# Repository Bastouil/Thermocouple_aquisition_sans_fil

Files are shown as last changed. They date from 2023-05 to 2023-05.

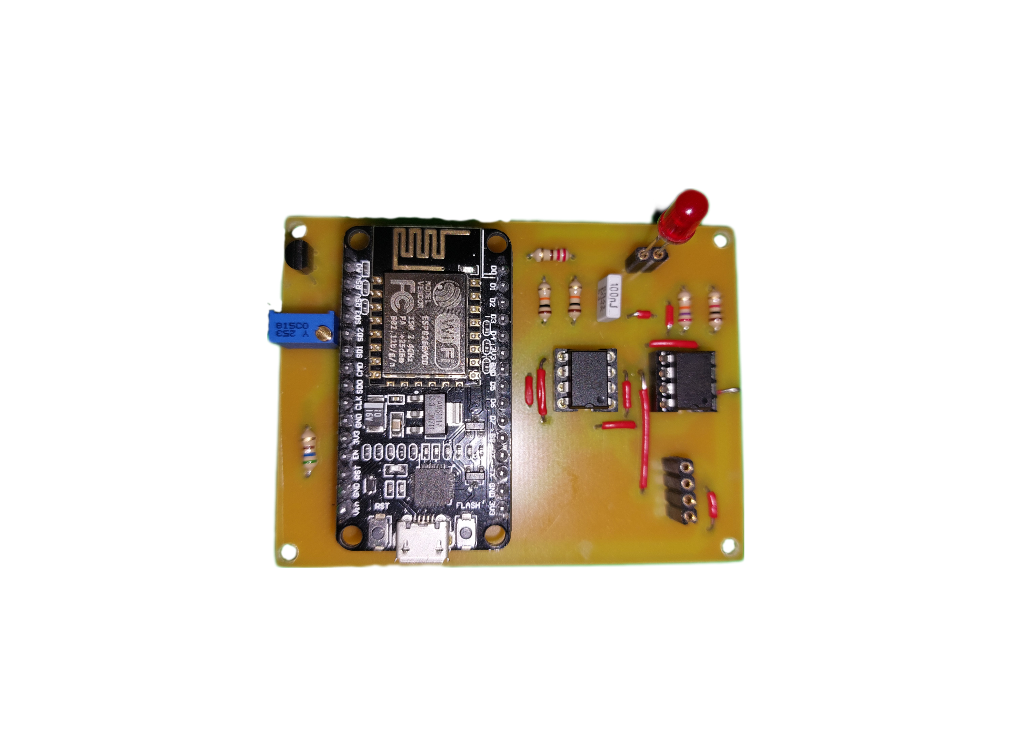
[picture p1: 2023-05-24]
Banque_images/BackgroundEraser_20230427_111905580.png

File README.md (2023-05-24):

# Thermocouple_aquisition_sans_fil
Le but du projet est de créer un thermocouple ayant un moyen d’acquisition sans fil. Les données seront envoyées par protocole WIFI afin d'être affichées et enregistrées sur un ordinateur.

La structure de l'archive du projet est la suivante :

-Banque_images :
	Dossier comprenant des photos, captures d'écran... du produit et des tests

-Circuit_imprime :
	Dossier qui contient les fichiers EAGLE du circuit électronique et du routage du PCB,
	ainsi que les fichiers PDF associés

-Datasheets :
	Dossier contenant les datasheets de chaque composant utilisé : 
	ESP8266 (nodeMCU), MCP3301, MCP6002 et LM335Z

-Documents_produits :
	Vous trouverez dans ce dossier le document de cadrage, l'énoncé du projet,
	les diapositives des 2 jalons, le rapport du projet ainsi qu'un manuel d'utilisation pour le thermocouple

-Programmes :
	Ce dossier contient un sous dossier contenant le programme entré dans le microcontroleur ESP8266
	(serveur TCP) écrit en cpp dans l'IDE ARDUINO, un second sous dossier contenant un programme principal écrit en Python
	(script client TCP lancé sur un ordinateur) faisant appel à un second programme contenant certaines fonctions pour alléger
	le code et enfin un manuel d'utilisation en pdf appelé par le code. Un code C émulant la conversion de tension en température, 	prenant en compte la compensation de la soudure froide est également contenu dans ce dossier

-Modelisation_CAO_boitier :
	Dossier comprenant les conceptions 3D sur FUSION 360 de chacun des composants du boitier,
	ainsi que la modélisation du produit

JAOUANNE Lilian & GARCON Bastian

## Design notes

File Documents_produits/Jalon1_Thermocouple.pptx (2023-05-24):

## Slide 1

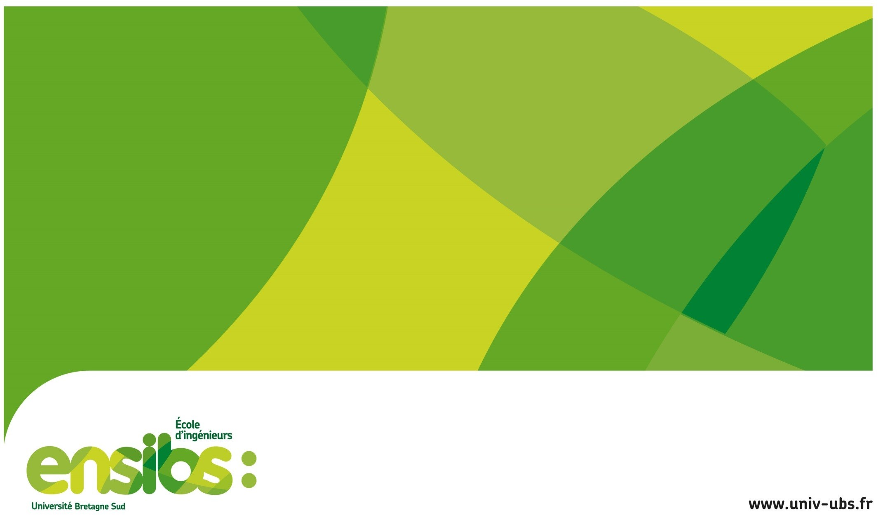
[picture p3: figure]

PRJ1401 - THERMOCOUPLE

Jalon intermédiaire
JAOUANNE Lilian
GARÇON Bastian

## Introduction

GARÇON JAOUANNE

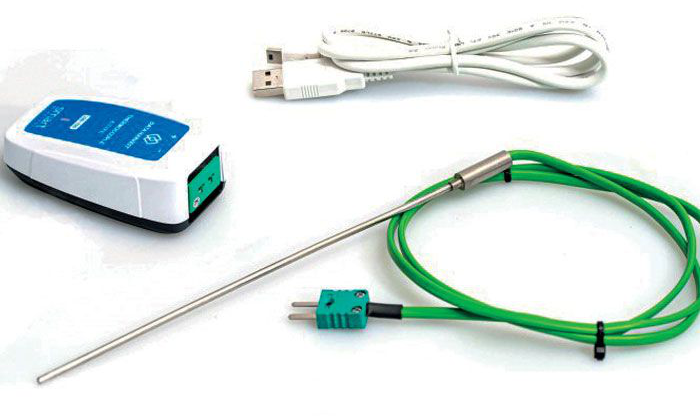
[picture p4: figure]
Bluetooth Wireless Smart K-Type Thermocouple -200°C to 1000°C / Capteur de température avec Thermocouple de type K

- Plage de températures : -200 à 1200°C
- Acquisition sans fils
- Résolution inférieur à 1°C
- Autonome en énergie

Client du projet : Hervé LAURENT, ENSIBS Mécatronique

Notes: Rappel du sujet.

## Sommaire

- Planification du projet
- Compensation soudure froide
- Conversion de la tension en température
- Matériaux utilisées
- Conversion analogique numérique de la tension
- Acquisition sans fil
- Tâches à réalisées

## Planification du projet

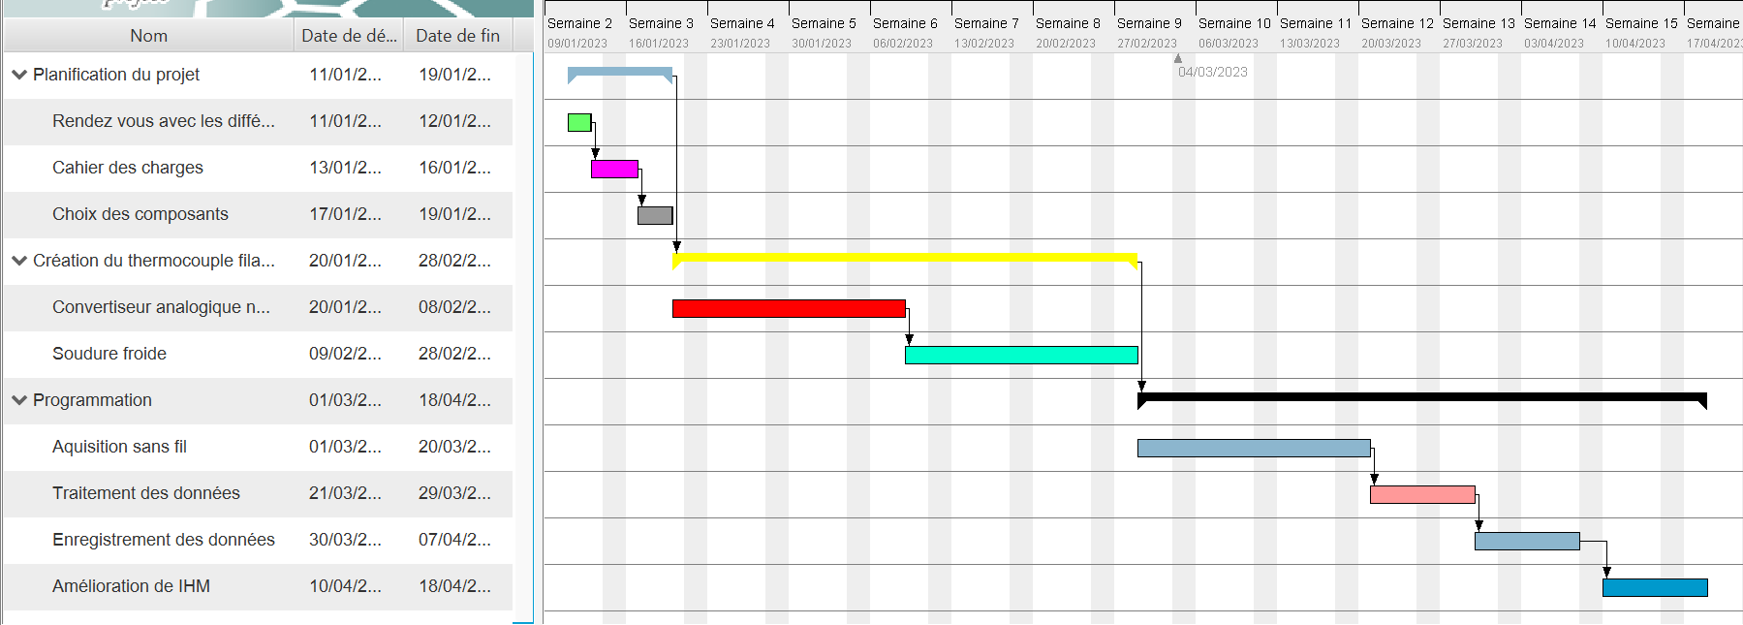
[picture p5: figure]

## Compensation soudure froide

E_(AB) (T_(0^(′)) ,T_0 )+E_(AB) (T_1 ,T_(0^(′)) )=E_(AB) (T_1 ,T_0 )

A

V

T_(0^(′))

T_1

B

Avec T_0 =0°C

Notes: Un thermocouple est un capteur actif de température. Il est composé de deux jonctions reliant deux métaux ou alliages différents. Le thermocouple fonctionne grâce à l’effet Seebeck qui produit un courant continu lorsqu'il y a une différence de température entre les deux jonctions. En ouvrant le circuit, on mesure une tension de faible niveau, mais mesurable (centaine de µV). Le thermocouple mesure la différence de température entre le point de mesure (SF – soudure froide) et le point de raccordement (SC – soudure chaude).
Température de la soudure froide doit être connu.

## Conversion tension / température

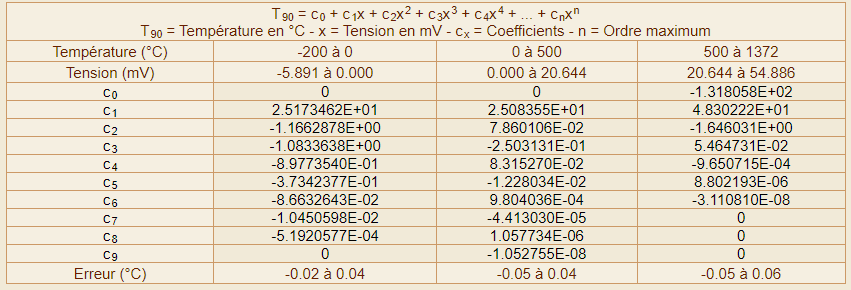
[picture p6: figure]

Tension -> Température

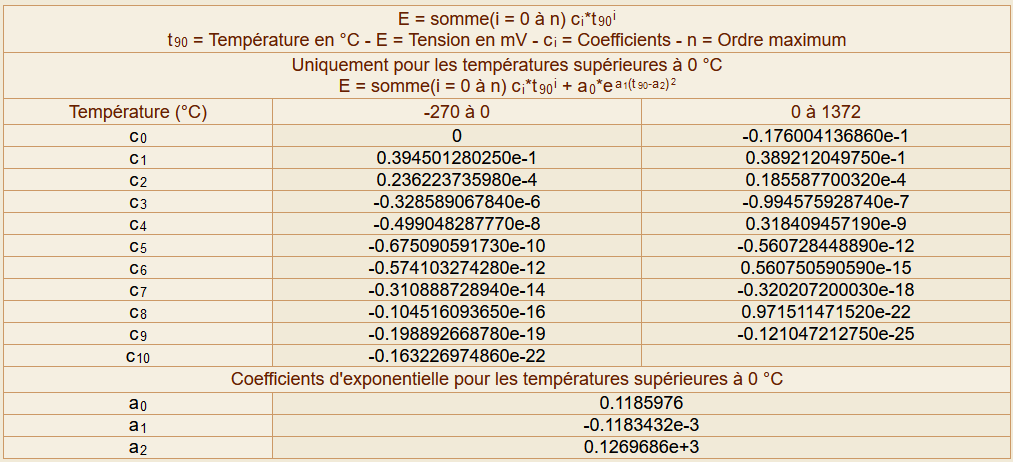
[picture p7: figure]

Température -> Tension

V

E_(AB) (T_(0^(′)) ,T_0 )+E_(AB) (T_1 ,T_(0^(′)) )=E_(AB) (T_1 ,T_0 )

## Matériaux utilisés

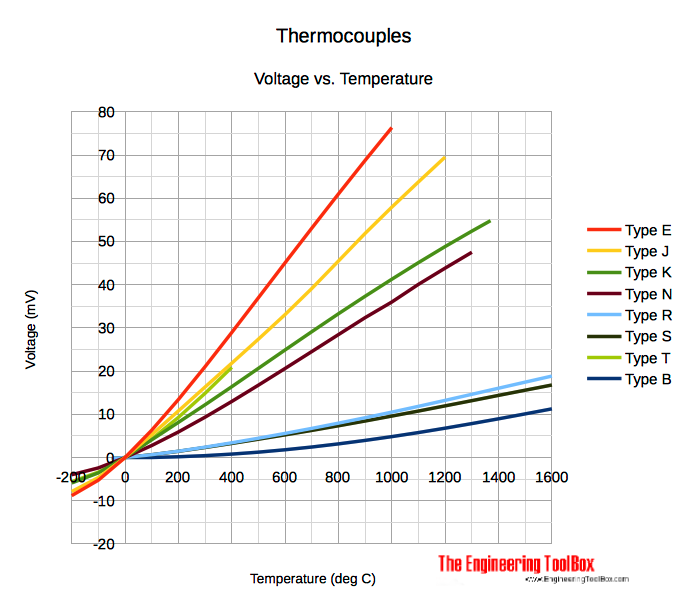
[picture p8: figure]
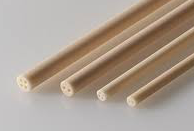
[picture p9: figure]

alumine

Chromel – Alumel (125 µm)

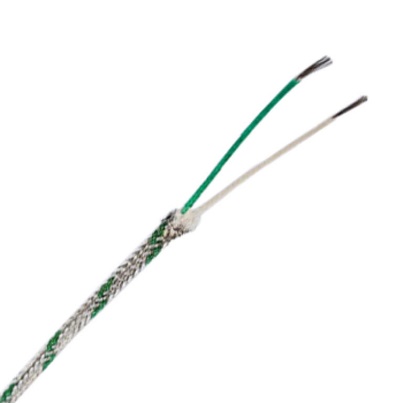
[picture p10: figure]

Soie de verre

## Conversion analogique numérique

Résolution= (Vref)/4096 = 24,4 µV avec Vref = 100 mV

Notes: Pourquoi ce choix ? CAN 12 bits + 1 bit signe, communication SPI

## Conversion analogique numérique

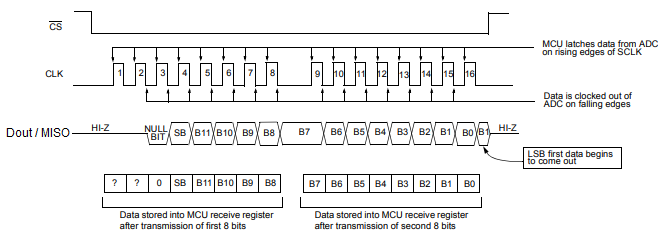
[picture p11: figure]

Mode de cadencement SPI : 0
- Polarité d’horloge (CPOL = 0) : Horloge en veille à l’état logique 0
- Phase d’horloge (CPHA = 0) : Cadencement des données sur le front montant

## Conversion analogique numérique

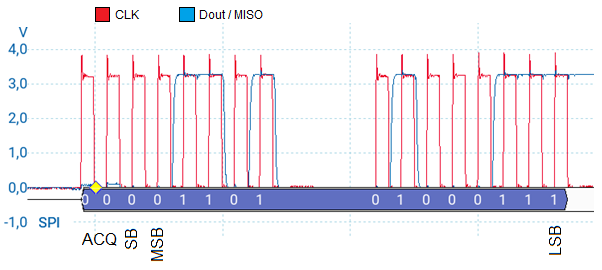
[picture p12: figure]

(0 0110 1010 0011)_(2S) = 3399_10

Tension = 3399 ×1000 × (Vref)/4095=82 mV , avec Vref = 100mV

## Acquisition sans fils

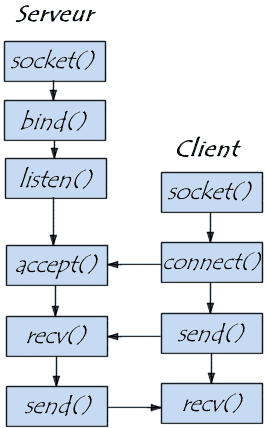
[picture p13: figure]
Déroulement d'une communication avec les sockets
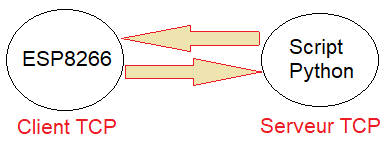
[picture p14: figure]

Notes: Choix ESP8266 point acces wifi programmé en cpp sur l’IDE Arduino

## Acquisition sans fils

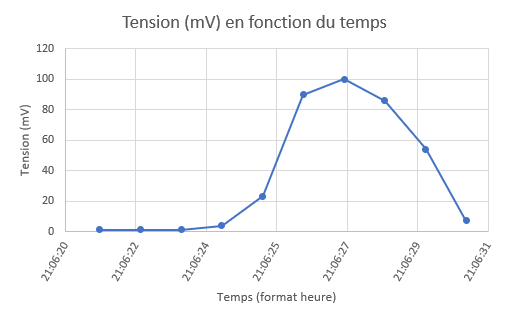
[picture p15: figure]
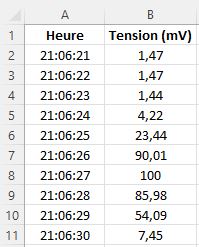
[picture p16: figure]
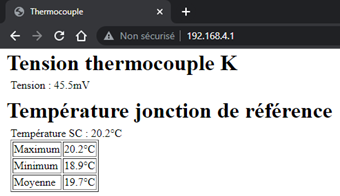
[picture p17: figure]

## Schéma électronique

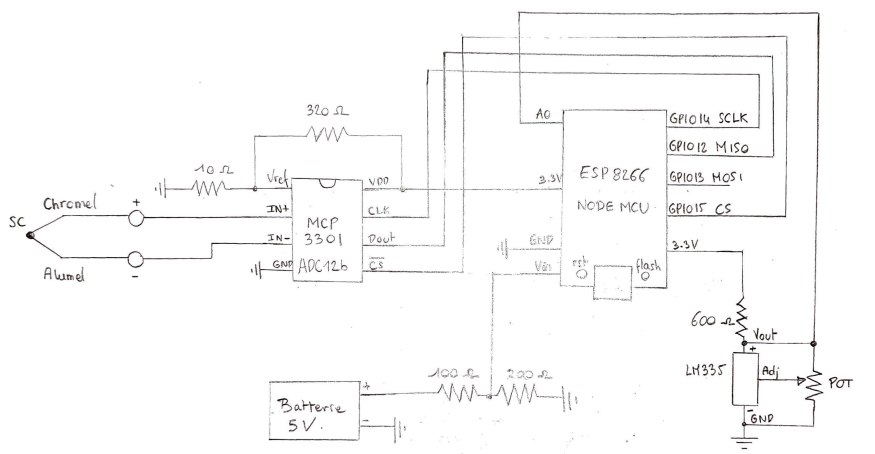
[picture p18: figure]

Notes: Conclusion de notre system et parler du capteur de température.

## Tâches à réaliser

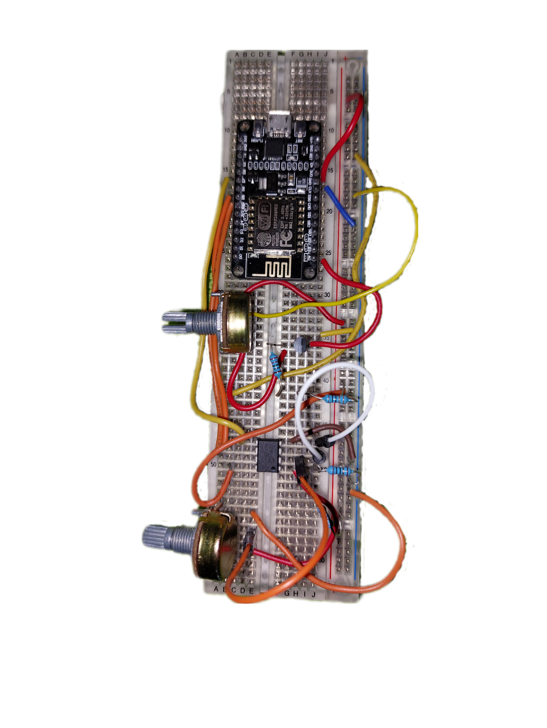
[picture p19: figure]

- Modélisation CAO d’un boîtier en PLA
- Maquettage de l’électronique (PCB)
- Alimentation
- Connecter l’ordinateur sur lequel est lancé le script au réseau wifi de l’ESP8266
- Créer un guide d’utilisation

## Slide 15

PRJ1401 - THERMOCOUPLE

Jalon intermédiaire
JAOUANNE Lilian
GARÇON Bastian

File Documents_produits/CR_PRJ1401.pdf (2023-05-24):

Lilian JAOUANNE & Bastian GARCON | 04/2023

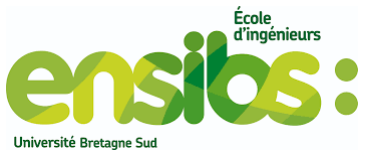
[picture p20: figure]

PEI2 / L2-SNIO – PRJ1401

# PRJ1401 : Rapport Projet Thermocouple Wifi

## Table des matières

## GARCON Bastian JAOUANNE Lilian

## I. Introduction

L’objectif de ce projet consiste à développer un thermocouple et d’acquérir la valeur de la température par un moyen sans fil (Bluetooth, Wifi…) sur une centrale d’acquisition. Le thermocouple devra pouvoir fonctionner sur une plage de température de -200 à 1200°C.

Bien que ce type de thermocouple existe déjà sur le marché, il nous ait demandé d’en concevoir un à partir des moyens disponibles à l’ENSIBS et si possible à bas coût.

## II. Principe de fonctionnement d’un thermocouple

Le principe du thermocouple consiste à mesurer une différence de potentiel entre deux fils constitués de deux conducteurs différents et soudés entre eux à une extrémité.

La mesure s’effectue ponctuellement au niveau de la soudure (nommée soudure chaude ou jonction de référence).

Un thermocouple est un capteur actif de température. Il est composé de deux jonctions reliant deux métaux ou alliages différents. Le thermocouple fonctionne grâce à l’effet Seebeck (Cf Erreur ! Source du renvoi introuvable.) qui produit un courant continu lorsqu'il y a une différence de température entre les deux jonctions. En ouvrant le circuit, on mesure une force électromotrice (tension) de faible niveau, mais mesurable (centaine de µV). Le thermocouple mesure la différence de température entre le point de mesure (SF – soudure froide) et le point de raccordement (SC – soudure chaude).

Pour s'assurer que la température ambiante aux bornes de raccordement de la soudure froide (idéalement 0°C) n'affecte pas le résultat de la mesure, une compensation de soudure froide est nécessaire.

La tolérance d’un thermocouple est généralement de ± 1°C. La soudure chaude peut être générée à partir d’un arc électrique et les fils qui composent le thermocouple (ou câbles d'extension/compensation) ont une couleur caractéristique normalisée. Le conducteur négatif est toujours blanc, le conducteur positif est toujours de la couleur de la gaine. Chaque paire de conducteurs définit une plage de mesure et un graphe associé, nommé par une lettre.

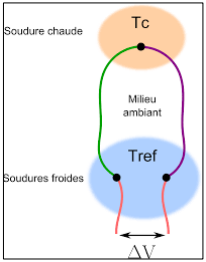
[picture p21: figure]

Figure 1 : Principe du thermocouple

## III. Définition du cahier des charges

- Plage de températures : -200 à 1200°C
- Acquisition sans fils
- Résolution correcte
- Fréquence d’échantillonnage 10Hz minimum
- Autonome en énergie

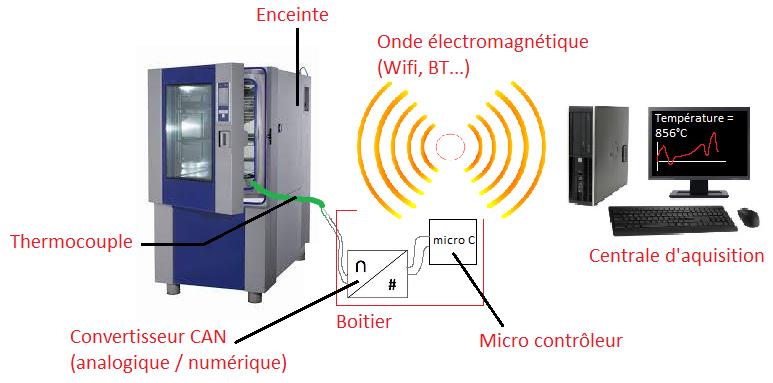
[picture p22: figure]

Figure 2 : Schéma du dispositif envisagé.

- Moyen d’acquisition

Pour le traitement du signal, il faudra un convertisseur analogique numérique (choisi en fonction de son nombre de bits) ou d’un module de récupération directe de la température devant renvoyer la donnée mesurée à un microcontrôleur. Microcontrôleur qui devra ensuite pouvoir traiter la différence de potentiel et la température de la jonction de mesure, puis transmettre la donnée par Bluetooth ou Wifi à un moyen d’acquisition (poste informatique, smartphone…).

La centrale d’acquisition devra ensuite récupérer la donnée émise et gérer son affichage.

Une solution serait le développement d’une application avec un script Python, affichant des informations sur la série de mesures dans le terminal par exemple.

- Autonomie

L’ensemble devra avoir sa propre source d’alimentation, il ne devra pas être relié à un secteur d’alimentation. De plus, le moyen d’alimentation devra assurer une durée de fonctionnement correct et répondre aux impulsions de consommations importantes demandées par le Bluetooth et le Wifi.

- Design

L’ensemble devra avoir une ergonomie compacte et discrète. Les fils du thermocouple sortiront de l’enceinte isolée thermiquement et être reliés à un boîtier situé à côté de l’enceinte (à l’extérieur). Boitier possiblement imprimé en 3D avec du PLA, dans lequel se trouveront les composants propres au traitement et à l’émission du signal.

## IV. Type de thermocouple utilisé et choix des isolants

Pour choisir notre type de thermocouple, nous nous sommes aidés du graphe en Figure 3. Premièrement, nous avons procéder par élimination grâce à la plage de température que nous impose le cahier des charges. De cette manière, nous savons que les thermocouples de types E, J et T (cf. Figure
3) ne sont pas envisageable puisque leur plage de fonctionnement s’arrête avant 1200 °C.

Nous avons donc le choix entre les 5 autres thermocouples (types K, R, N, S et B).

Finalement, nous avons choisi d’utiliser un thermocouple de type K car c’est celui qui possède la plus grande variation de tension en fonction de la température. Ce critère est important puisqu’il influera sur la précision de notre thermocouple.

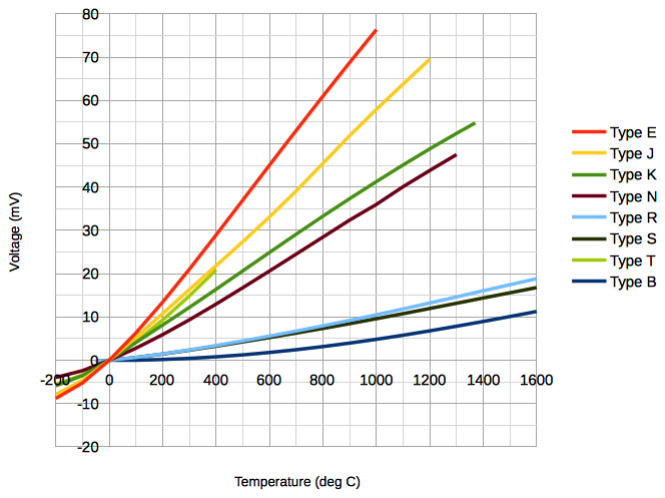
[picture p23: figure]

Figure 3 : courbes de tensions en fonction de la température pour différents types de thermocouples.

Concernant le choix des isolants, nous avons choisi d’utiliser un tube d’alumine (cf. Figure 4) pour le bout du thermocouple car l’alumine est un isolant électrique résistant à de très haute température (1800°C). Pour le reste de la gaine, nous utilisons de la soie de verre (cf. Figure 5) puisque que contrairement à l’alumine, la soie de verre est plutôt flexible ce qui rend la manipulation de la gaine plus simple pour les mesures de température. En revanche, la soie de verre se cristallise à partir d’environ 600 °C. C’est pourquoi nous ne l’avons pas utilisée pour l’ensemble de la gaine.

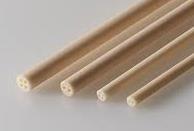
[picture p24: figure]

Figure 4 : tubes d'alumines.

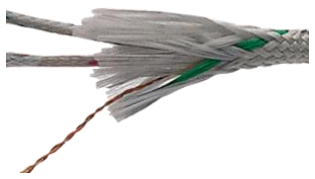
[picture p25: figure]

Figure 5 : soie de verre.

## V. Compensation de la soudure froide

La compensation de la soudure froide est une étape incontournable dans la création d’un thermocouple puisque la tension aux bornes de la soudure chaude va dépendre de la température de la soudure froide. De plus dans les tableaux de conversions pour un type de thermocouple donné, on considère que la température de la soudure froide est de 0°C.

A partir de la tension aux bornes de la soudure chaude et de la température aux bornes de la soudure froide, il est possible de compenser cette dernière grâce à la formule suivante :

EAB(T0
′ , T0

) + EAB(T1, T0

′ ) = EAB(T1, T0

)

Avec :

- EAB(T0
′ , T0

) : la tension virtuelle de la soudure froide¹
- EAB(T1, T0

′ ) : la tension aux bornes de la soudure chaude
- EAB(T1, T0

) : la tension aux bornes de la soudure chaude compensée

On obtient alors la tension compensé EAB(T1, T0

), qu’il noussuffit de convertir en température à l’aide des tables de conversion du type de thermocouple utilisé afin d’obtenir la température absolue à la soudure chaude.

Pour connaître la température de la soudure froide (approximée à la température ambiante dans le boîtier du thermocouple), nous utilisons un capteur de température LM335Z avec le montage suivant (cf. Figure 6) :

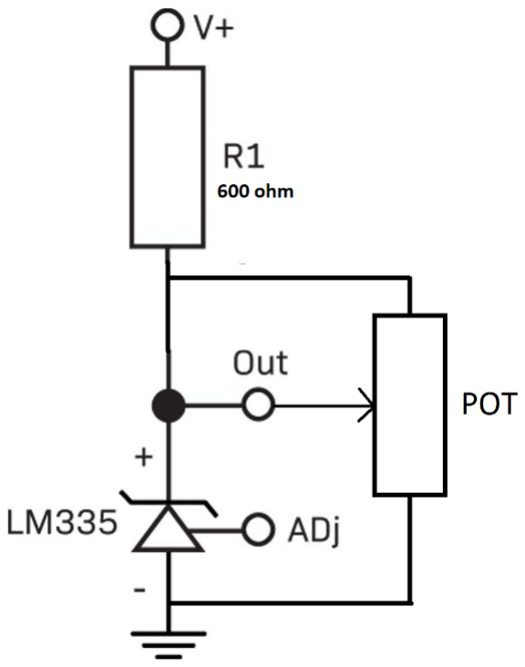
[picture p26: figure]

Figure 6 : Schéma circuit LM335.

Un potentiomètre (cf. Figure 6, POT) permet de calibrer manuellement la valeur de la température relevée.

1 Tension obtenue en convertissant la température de la soudure froide à l’aide des tables de conversion du type de thermocouple utilisé

## VI. Schéma électronique

### 1. Circuit d’amplification

Pour mesurer la tension aux bornes de la soudure chaude avec une précision suffisante²
, nous
devons utiliser un circuit d’amplification. Pour cela, nous utilisons premièrement un montage différentiel (cf. Figure 7, cercle rouge) pour amplifier le signal et un montage suiveur (cf. Figure 7, cercle vert) pour stabiliser la tension « Offset » qui va permettre de mesurer des tensions négatives.

Vref

Figure 7 : schéma du circuit d'amplification.

En considérant les propriétés des AOP, on trouve le gain G suivant :

G =

R1 + R2
R1

En sachant que les tensions que mesurera notre thermocouple vont de -5,891 mV (pour une soudure chaude à -200 °C) à 48,838 mV (pour une soudure chaude à 1200 °C) et que notre convertisseur analogique numérique ne mesurera des valeurs allant de 0 à 3,3V, nous devrons alors avoir un gain d’environ :

2 ± 42 µV pour avoir une pression de ± 1 °C

3300 − 0
48,838 − (−5,891)

≈ 60

En sachant que nous ajoutons une tension « Offset » de ³,3
2

pour amplifier les tensions négatives, nous devrons donc amplifier avec une valeur étant aux alentour de 30 (la moitié de 60). Pour être sûr que notre AOP ne sature pas, on prend un gain légèrement inférieur à 30.

Sur la Figure 7 on voit que notre gain est de :

1 + 27
1

= 28

Dans la pratique, notre gain est d’environ 28,11 puisque les résistances R1 et R2 ne font pas exactement 1 kΩ et 27 kΩ.

Pour tester le circuit d’amplification, nous avons généré des signaux continus d’amplitudes comprises entre -6 mV et 50 mV (plage de tension du thermocouple de type K) à l’aide d’un Picoscope 2000.

### 2. Conversion analogique numérique

L’unique entrée analogiques du microcontrôleur ESP8266 n’étant codée que sur 10 bits (2

10 =
1024 valeurs possibles) et l’ESP8266 étant alimenté en 3,3V soit 3300 mV, cette entrée nous donne donc une résolution de ³³⁰⁰
1024

≈ 3,22 mV.

Or, la plage de tension en sortie du thermocouple pour des températures allant de -200 à 1200°C (amplitude de 1400°C) est comprise entre -5 et 50 mV soit une amplitude de valeurs de 55 mV. Avec une résolution de 3,22 mV, nous aurions alors pour une plage de tension de 55 mV, 55
3,22

≈ 17,08
valeurs possibles.

Ce qui correspond à une résolution en température de 1400
17,08

≈ 82°C sans l’utilisation d’AOP.

Par soucis de précision, nous utiliserons donc le convertisseur analogique 13 bits MCP3301 avec communication SPI. Cet ADC est codé sur 12 bits avec en plus un bit de signe. Alimenté en 3,3 V, il nous donnera donc une résolution de ³³⁰⁰
2

13 ≈ 0,4 mV et donc

55
0,4

≈ 137,5 valeurs possibles. Il nous donne donc une résolution en température de 1400
| 137,5 ≈ 10°C sans AOP.

Le MCP3301 (esclave) communiquera avec l’ESP8266 (maitre) suivant le protocole de communication SPI mode 0.

Mode de cadencement SPI : 0

- Polarité d’horloge (CPOL = 0) : Horloge en veille à l’état logique 0
- Phase d’horloge (CPHA = 0) : Cadencement des données sur le front montant

Un pin CS (chip select) de sélection de puce permet lorsqu’il est forcé à l’état bas, d’activer la communication avec le maitre (ESP8266). La trame (cf. Figure 8) envoyée sur la sortie MISO (master input slave output) permet l’échange de données (valeur de tension différentielle en entrée du convertisseur) vers le maitre, cadencé par une horloge CLK.

Remarque : Le MCP3301 ne comporte pas de pin MOSI (master output slave input), rendant ainsi impossible l’envoi de données du maitre vers l’ADC.


Figure 8 : détail de la trame du MCP3301.

La fréquence d’horloge du MCP3301 est fclk = 1,7 MHz et une trame est codée sur 17 cycles d’horloges. On en déduit que la fréquence d’échantillonnage du convertisseur est fsamples =

fclk
17

=
100 kHz.

Un exemple de trame SPI décodée au Picoscope est le suivant (cf. Figure 9) :


Figure 9 : trame SPI décodée au Picoscope.

On a alors : (0 0110 1010 0011)2S = 339910

Et Tension = 3399 × 1000 ×

Vref
4096

= 2738 mV, avec Vref = 3,3 V

Note : Vref est une broche du composant qui prend en entrée une tension de référence qui influe directement sur la résolution du convertisseur

### 3. Création d’un PCB

Le PCB a été fait à l’aide du logiciel EAGLE. Nous avons commencé par faire notre schéma électronique (cf. Figure 10) puis nous avons dû router(créer des pistes de cuivre pour relier les broches des composants) le PCB avant son impression (cf. Figure 11). Le PCB à deux couches, une couche appelée « bottom » constituée de pistes de cuivre et une couche côté composant « top » sur laquelle on utilise des fils apparents pour faire les liaisons. Des vias permettent de faire le lien entre certaines pistes de la couche « bottom » et de celles de la couche « top ».


Figure 10 : schéma électronique du thermocouple sous EAGLE.


Figure 11 : routage du PCB sous EAGLE.


Figure 12 : Photos du PCB après les soudures des connecteurs et l’ajout des composants.

## VII. Alimentation du thermocouple

L’ESP8266 dispose d’un régulateur linéaire de tension vers 3,3 V. La consommation du microcontrôleur est de 300 mA en mode point d’accès Wifi (Le mode AP empêche les modes de veilles). Nous avons choisi des pile AAA non rechargeable pour l’alimentation de notre système.

En sachant les informations suivantes :

Tension : 1,5 V

Capacité : 2500 mAh

3 piles AAA de 1,5 V en série ⇔ 4,5 V

Nous avons pu déduire l’autonomie de notre système lorsque celui-ci utiliser le Wifi.

2500
300 ≈ 8h 30min

Notre système peut donc fonctionner pendant 8h30 avec le Wifi de l’ESP8266 d’activé.

Remarque : Des piles AAA rechargeables pourraient aussi être envisagées. Ayant individuellement une tension nominale de 1,2 V, il serait judicieux d’en mettre 4 en série de sorte à obtenir une tension d’alimentation de 4,8 V (de sorte à anticiper la décharge des piles).

## VIII. Modélisation 3D du boitier

Le PCB modélisé sur EAGLE à pu être importé sur FUSION 360 (deux logiciels de la suite AUTODESK).

L’assemblage comprend un boitier, un couvercle, un interrupteur permettant d’alimenter ou non le circuit ainsi qu’un connecteur femelle de thermocouple de type K destiné à connecter les deux fils (chromel et alumel) du thermocouple.


Figure 13 : modélisation du boitier sous fusion 360.

## IX. Programmation de l’ESP8266


Figure 14: schéma serveur client.

Le script python connecté au point d’accès WiFi établi une connexion TCP avec le serveur.

Des tables de conversions propres aux thermocouples de type K permettent de retrouver la température de la soudure chaude.

Note : Bien que la fréquence d’échantillonnage du convertisseur analogique numérique MCP3301 soit de 100 kHz, on réduira la fréquence d’acquisition de la mesure à 10 Hz soit 100 ms ou encore 0,1 seconde, pour que le script Python lancé sur un ordinateur puisse correctement réceptionner les données par Wifi.

## X. Application Python

L’application a été écrite en Python avec la bibliothèque TKINTER permettant l’affichage de fenêtres.

Le fichier au format PY a ensuite été converti en EXE grâce à la commande «auto-py-to-exe» dans la console de Visual Studio Code.

Une fois l’application lancée, la fenêtre suivante s’ouvre (cf. Figure 15) :


Figure 15 : interface principale de l'application.

L’ordinateur sur lequel est lancé l’application doit être connecté au réseau Wifi généré par l’ESP8266 :

Note : Un manuel d’utilisation permettant la prise en main du logiciel et du dispositif thermocouple est disponible depuis l’onglet Aide/Utilisation de l’application.

Les données résultantes de l’acquisition Wifi sont alors enregistrées dans un fichier suivant la norme CVS (compatible avec le format XLS d’EXCEL) (exemple en Figure 16).

Figure 16 : exemple d'ouverture d'un fichier CSV avec Excel.

La première colonne du tableau (cf. Figure 16) correspond à l’horloge de la réception des trames Wifi par l’application (script python lancé sur un ordinateur) et la seconde colonne nous donne quant à elle la température mesurée localement. Il est alors possible de traiter ses données en traçant un graphique comme en Figure 17 :


Figure 17 : exemple de graphique Excel avec les données en Figure 16.

## XI. Conclusion

Ce projet nous aura permis de travailler en groupe touchant aux trois domaines fondamentaux de la mécatronique. Nous aurons notamment pu nous familiariser avec des logiciels de la suite AUTODESK et utiliser le matériel / machines de l’atelier de l’ENSIBS.

D’éventuelles reprises du projet pourraient être envisagées :

- Passer l’ESP8266 en mode station Wifi de sorte à pouvoir le déconnecter du réseau et ainsi utiliser les différents modes de veilles
- Compatibilité avec d’autres types de thermocouples (K, J, E…) sélectionnables depuis l’application

## XII. Ressources et personnel sollicités

### 1. Ressources

Pour ce projet, nous avons utiliser les différents outils présents au sein de l’ENSIBS de Lorient notamment ceux se trouvant dans le laboratoire de mécatronique (CNC pour le PCB).

Pour le matériel, nous avons pu prélever les composants prévus à cet effet, pour la fabrication de notre thermocouple à l’ENSIBS.

Enfin, si le matériel n’est pas disponible au sein de l’école. Nous avons pu en commander sur les sites partenaires.

Liens ressources :

- https://fr.wikipedia.org/wiki/Thermocouple, consulté le 15/01/2023
- https://www.youtube.com/watch?v=7QFdb2aJn14, consulté le 03/02/2023
- https://aviatechno.net/thermo/thermo03.php, consulté le 03/02/2023

Liens des images :

- Figure 3 : https://www.engineeringtoolbox.com/thermocouples-d_496.html, consulté le 26/02/2023
- Figure 4 : https://www.umicore-ceramics.com/fr/produits-en-ceramiques-techniques/tubes-en-alumine/capillaire-alumine, (https://www.umicore-ceramics.com/fr/produits-en-ceramiques-techniques/tubes-en-alumine/capillaire-alumine) consulté le 16/03/2023
- | Figure | 5 : | https://www.sab-cable.eu/produits/cables-de-compensation-dextension/th-
lgs.html, (https://www.sab-cable.eu/produits/cables-de-compensation-dextension/th-lgs.html) consulté le 10/05/2023

### 2. Personnel

Lors de ce projet, nous nous sommes référés à différentes personnes spécialistes dans leur domaine afin d’obtenir des précisions sur différents sujets. Avec notamment :

- Hervé LAURENT tuteur / client du projet. Il nous a notamment apporté des précisions sur le cahier des charges, suivie générale du projet et visite du laboratoire LAB-STICC.
- William BERCKMANS qui est un chercheur au LAB-STICC. Il est un spécialiste des thermocouples. Il nous a donc éclairé pour la conception de celui-ci (épaisseur des fils, choix du matériau, soudage…) et nous aussi donné du matériel (lecteur de thermocouple, câbles de thermocouple, connecteur …).
- Philippe GICQUEL, aide portée sur le circuit d’amplification des AOP (MCP6002), la modélisation du circuit électronique sur EAGLE ainsi que l’impression du PCB à la CNC.
- Florent DE LAMOTTE professeur de Mécatronique, aide concernant le choix de l’alimentation au vu de la consommation de l’ESP8266 et des éventuels modes de veilles du microcontrôleur.
- Cédric SEGUIN, professeur à l’ENSIBS. Aide sur l’envoi des trames SPI du MCP3301 (ADC 13 bits) et décodage avec un Picoscope 2000.

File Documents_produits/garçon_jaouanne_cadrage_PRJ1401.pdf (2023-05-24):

JAOUANNE Lilian GARÇON Bastian | 13 janvier 2023
L2 SNIO / PEI2 | 1

## PRJ 1404

### GARÇON Bastian & JAOUANNE Lilian

### Client : LAURENT Hervé

__________________________________________________________________________________

## Table des matières

## Objectif :

L’objet de ce projet consiste à développer un thermocouple et d’acquérir la valeur de la température par un moyen sans fil (Bluetooth, Wifi…) sur une centrale d’acquisition. Le thermocouple devra pouvoir fonctionner sur une plage de température de -200 à 1200°C.

Bien que ce type de thermocouple existe déjà sur le marché, il nous ait demandé d’en concevoir un à partir des moyens disponibles à l’ENSIBS et si possible à bas coût.

# Thermocouple Document de cadrage


L2 SNIO / PEI2 | 2

## Fonctionnement du thermocouple :

Le principe du thermocouple consiste à mesurer une différence de potentiel entre deux fils constitués de deux conducteurs différents et soudés entre eux à une extrémité.

La mesure s’effectue ponctuellement au niveau de la soudure (nommée soudure chaude ou jonction de référence).

Un thermocouple est un capteur actif de température. Il est composé de deux jonctions reliant deux métaux ou alliages différents. Le thermocouple fonctionne grâce à l’effet Seebeck (Cf Bibliographie) qui produit un courant continu lorsqu'il y a une différence de température entre les deux jonctions. En ouvrant le circuit, on mesure une force électromotrice (tension) de faible niveau, mais mesurable (centaine de µV). Le thermocouple mesure la différence de température entre le point de mesure (SF – soudure froide) et le point de raccordement (SC – soudure chaude).

Pour s'assurer que la température ambiante aux bornes de raccordement de la soudure froide (idéalement 0°C) n'affecte pas le résultat de la mesure, une compensation de soudure froide est nécessaire.

La tolérance d’un thermocouple est généralement de ± 1°C. La soudure chaude peut être générée à partir d’un arc électrique et les fils qui composent le thermocouple (ou câbles d'extension/compensation) ont une couleur caractéristique normalisée. Le conducteur négatif est toujours blanc, le conducteur positif est toujours de la couleur de la gaine. Chaque paire de conducteurs définit une plage de mesure et un graphe associé, nommé par une lettre.

Figure 1 : Principe du thermocouple


L2 SNIO / PEI2 | 3

## Cahier des charges :

Figure 2 : Schéma du dispositif envisagé

- Thermocouple

Il existe différents types de thermocouples suivant la plage de température à mesurer, différenciant le couple de matériaux semi-conducteurs à utiliser.

Nous prendrons un thermocouple de type K pour des températures allant de -270 à 1370°C avec une sensibilité de 41µV/°C. Le type K demande un fil de Chromel (alliage de Nickel et de Chrome) et un fil d’Alumel (alliage de Nickel et d’Aluminium).

La taille des 2 fils utilisés influencera sur la vitesse et la précision des mesures. Nous préférerons donc des fils fins et prendrons des fils de 250 microns.

Pour isoler électriquement nos deux fils, nous utiliserons un tube d’alumine (minéraux de température de fusion 2000°C) pour la partie à l’intérieur de l’enceinte et une isolation en soie de verre pour la partie des fils à l’extérieur (fusion à 300°C).

Pour compenser la température de référence de la soudure froide, il est nécessaire de connaître la température de la jonction de référence. On utilisera pour cela une thermistance CTN ou autre capteur de température.

- Moyen d’acquisition

Pour le traitement du signal, il faudra un convertisseur analogique numérique (choisi en fonction de son nombre de bits) ou d’un module de récupération directe de la température devant renvoyer la donnée mesurée à un microcontrôleur. Microcontrôleur qui devra ensuite pouvoir traiter la différence

L2 SNIO / PEI2 | 4

de potentiel et la température de la jonction de mesure, puis transmettre la donnée par Bluetooth ou Wifi à un moyen d’acquisition (poste informatique, smartphone…).

La centrale d’acquisition devra ensuite récupérer la donnée émise et gérer son affichage.

Une solution serait le développement d’une application avec un script Python, affichant des informations sur la série de mesures dans le terminal par exemple.

- Autonomie

L’ensemble devra avoir sa propre source d’alimentation, il ne devra pas être relié à un secteur d’alimentation. De plus, le moyen d’alimentation devra assurer une durée de fonctionnement correct et répondre aux impulsions de consommations importantes demandées par le Bluetooth et le Wifi.

- Design

L’ensemble devra avoir une ergonomie compacte et discrète. Les fils du thermocouple sortiront de l’enceinte isolée thermiquement et être reliés à un boîtier situé à côté de l’enceinte (à l’extérieur). Boitier possiblement imprimé en 3D avec du PLA, dans lequel se trouveront les composants propres au traitement et à l’émission du signal.

L2 SNIO / PEI2 | 5

## Ressource et personnel mis à notre disposition

### Ressources

Pour ce projet, nous pourrons utiliser les différents outils présents au sein de l’ENSIBS de Lorient notamment ceux se trouvant dans le laboratoire de mécatronique. Si nécessaire, nous devrons être supervisés par un enseignant lors de l’utilisation de ces derniers.

Pour le matériel, nous pourrons prélever les composants prévus à cet effet, pour la fabrication de notre thermocouple à l’ENSIBS.

Enfin, si le matériel n’est pas disponible au sein de l’école. Nous pourrons en commander sur les sites partenaires.

### Personnel

Lors de ce projet, nous pourrons aussi nous référer à différentes personnes spécialistes dans leur domaine afin d’obtenir des précisions sur différents sujets. Cela a déjà été le cas avec l’un des chercheurs au LAB-STICC, William BERCKMANS. William est un spécialiste des thermocouples. Il nous a donc éclairé pour la conception de celui-ci (épaisseur des fils, choix du matériau, soudage…) et nous aussi déjà donné du matériel (lecteur de thermocouple et câbles de thermocouple) pour débuter notre projet.

Quant à notre tuteur Hervé LAURENT, un mail lui sera envoyé après chaque session de projet. Avec à l’intérieur quelques phrases sur ce que nous avons fait durant la séance, mais aussi ce qu’il nous reste à faire pour les séances à venir. Quelquesrendez-vous seront aussi pris avec Hervé afin de faire le point sur l’avancement du projet.


L2 SNIO / PEI2 | 6

## Calendrier

date | événement du projet
lundi 12 décembre | début de la diffusion des sujets
vendredi 6 janvier | présentation du fonctionnement et des sujets
lundi 9 janvier | retour et diffusion des affectations étudiants/projets
vendredi 13 janvier | première séance de projet
vendredi 13 janvier | fin prises de rendez-vous et rencontre avec les tuteurs
vendredi 20 janvier | dépôt du document de Cadrage
vendredi 10 mars | dépôt diaporama du jalon
semaine 11 | jalon
vendredi 5 mai | dépôt diaporama de la soutenance
semaine 19 | soutenance
vendredi 12 mai | dépôt du rapport
vendredi 12 mai | dépôt de l’archive de reprise du projet

Tableau 1 : calendrier du projet

Figure 3 : Planification du projet fait sur GanttProject

L2 SNIO / PEI2 | 7

## Bibliographie

- EFFET SEEBECK
https://fr.wikipedia.org/wiki/Effet_Seebeck
- THERMOCOUPLE
https://fr.wikipedia.org/wiki/Thermocouplehttps://youtu.be/7QFdb2aJn14

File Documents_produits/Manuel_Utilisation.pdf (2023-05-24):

Lilian JAOUANNE & Bastian GARCON | 04/2023


PEI2 / L2-SNIO – PRJ1401

# Manuel d’utilisation

1. Mise sous tension du dispositif thermocouple en faisant basculer la position de l’interrupteur présent sur le boitier.


2. Brancher le connecteur du thermocouple de type K au bornier du boitier.

# Thermocouple WiFi


3. Lancer l’application « ThermoWiFi » sur un ordinateur, puis connecter l’ordinateur en question au point d’accès WiFi généré par l’ESP8266 du dispositif du thermocouple à l’aide des informations suivantes :
- SSID : Thermocouple-WiFi
- Password : ENSIBS2023


4. Calibrer le capteur de température de la soudure froide du thermocouple depuis la barre de menu de l’application sous « Réglages » puis « Soudure froide ».


Ouvrir le boitier du thermocouple et se munir d’un tournevis pour faire tourner le potentiomètre présent sur le circuit intégré du thermocouple, jusqu’à obtenir sur la valeur de la température ambiante dans la fenêtre de l’application, puis fermer la fenêtre.


5. Choisir un fichier au format « csv » (format Excel) dans lequel sauvegarder les valeurs lors de la mesure.
La sélection / création du fichier se fait depuis la barre de menu sous « Fichier » puis « Enregistrer ». Le chemin du fichier courant doit alors être affiché sur la fenêtre principale de l’application.
6. Lancer l’acquisition de données en cliquant sur le bouton « Start » et arrêter l’acquisition une fois les mesures effectuées en cliquant sur le bouton « Stop ». Remarque : La LED présente sur dessus du boitier du thermocouple clignotera durant l’acquisition.


7. Vous pouvez ensuite consulter / mettre en forme les données obtenues (valeurs de températures de la soudure chaude (en °C) en fonction du temps (en ms)) directement depuis l’application sous « Fichier » puis « Ouvrir » ou depuis votre explorateur de fichiers.


8. Des informations sur l’applications se trouvent dans la barre de menu sous « Aides » puis « A propos ».
9. Des informations complémentaires concernant l’utilisation de l’application se trouvent dans l’onglet « Aides » puis « Utilisation » de la barre de menu.

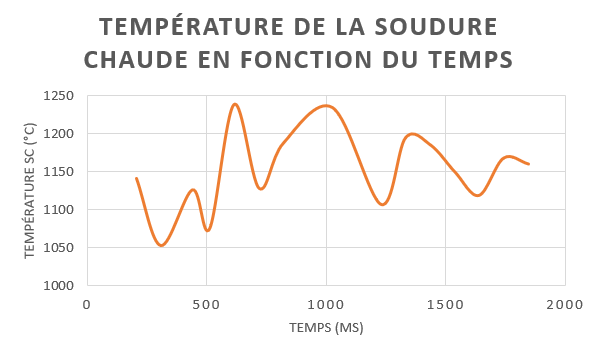
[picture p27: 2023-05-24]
Banque_images/graph.png

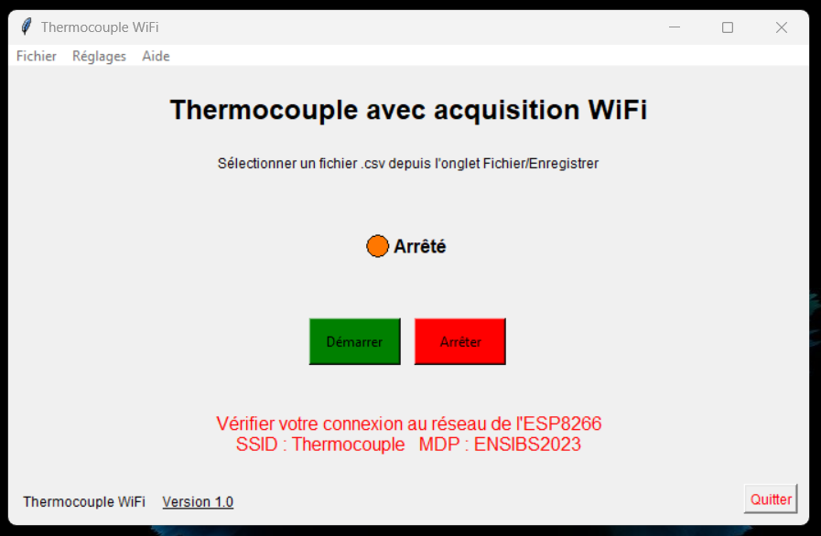
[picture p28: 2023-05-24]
Banque_images/erreur_connexion.png

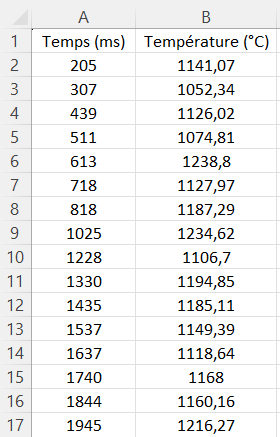
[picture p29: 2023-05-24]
Banque_images/donnees_excel.png

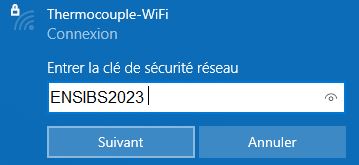
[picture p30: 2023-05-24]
Banque_images/connexion_wifi.JPG

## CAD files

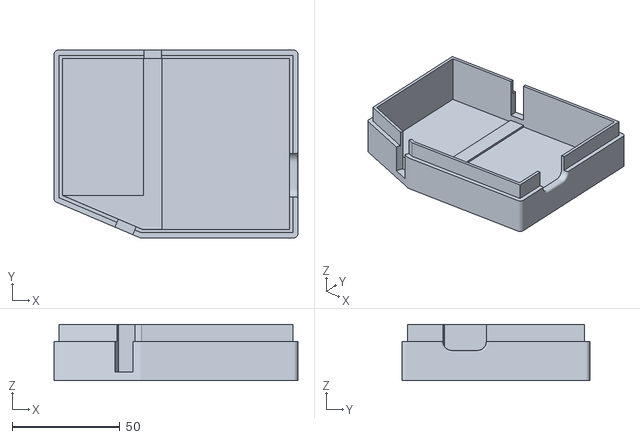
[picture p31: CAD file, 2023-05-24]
Modelisation_CAO_boitier/Boitier_ThermocoupleVF.STL
113.0 x 87.0 x 26.0

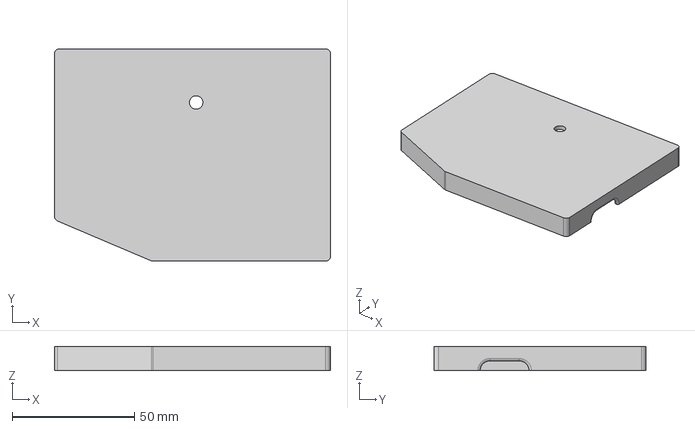
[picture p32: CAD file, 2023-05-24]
Modelisation_CAO_boitier/Couvercle_Thermocouple.step
113.0 x 87.0 x 10.0 mm

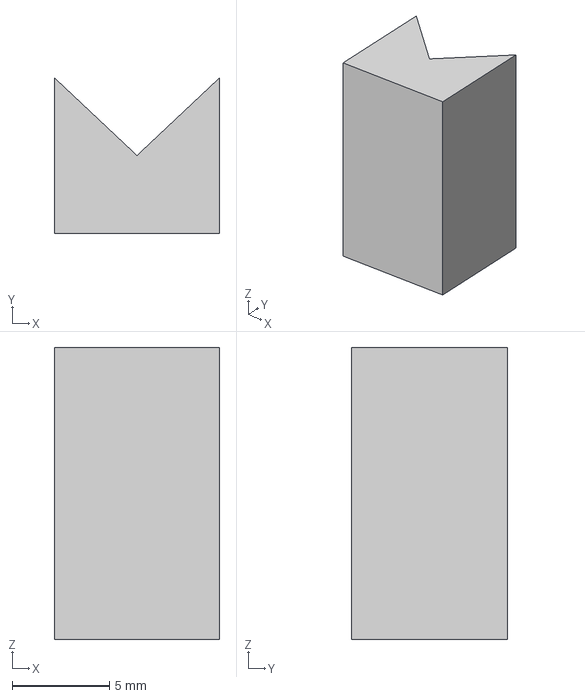
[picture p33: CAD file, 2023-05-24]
Modelisation_CAO_boitier/socle v1.step
8.50 x 8.00 x 15.0 mm

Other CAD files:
Modelisation_CAO_boitier/socle.STL
Modelisation_CAO_boitier/Assemblage_Thermocouple/0204_7.ipt
Modelisation_CAO_boitier/Assemblage_Thermocouple/1725672-4-2.54.ipt
Modelisation_CAO_boitier/Assemblage_Thermocouple/1x3 Male Pin Header.ipt
Modelisation_CAO_boitier/Assemblage_Thermocouple/1x4 Male Pin Header.ipt
Modelisation_CAO_boitier/Assemblage_Thermocouple/Assemblage_Thermocouple_V1.iam
Modelisation_CAO_boitier/Assemblage_Thermocouple/Board.ipt
Modelisation_CAO_boitier/Assemblage_Thermocouple/Boitier_3-piles-AAA v1.ipt
Modelisation_CAO_boitier/Assemblage_Thermocouple/Boitier_Thermocouple_V1 v6.ipt
Modelisation_CAO_boitier/Assemblage_Thermocouple/C050-025X075.ipt
Modelisation_CAO_boitier/Assemblage_Thermocouple/Connecteur_Thermocouple_femelle v1.ipt
Modelisation_CAO_boitier/Assemblage_Thermocouple/Couvercle_Thermocouple_V1 v11.ipt
Modelisation_CAO_boitier/Assemblage_Thermocouple/DIL08.ipt
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

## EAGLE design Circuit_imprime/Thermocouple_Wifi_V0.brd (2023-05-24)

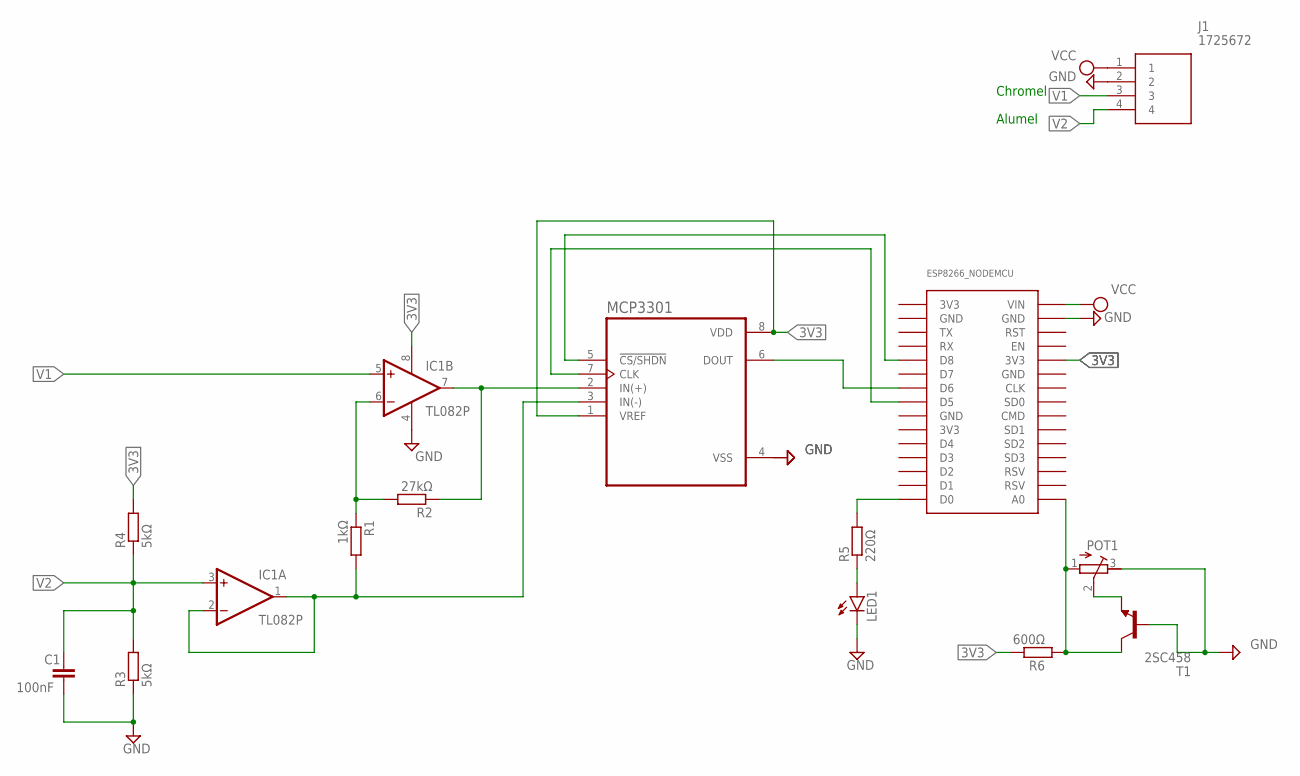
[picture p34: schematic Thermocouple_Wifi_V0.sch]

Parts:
C1: 100nF; C050-025X075
ESP8266_NODEMCU: NODEMCU_ESP8266
IC1: TL082P; DIL08
J1: 1725672; 1725672-4-2.54
LED1: LED5MM
MCP3301: MCP3301-CI/P; DIP787W46P254L927H533Q8
POT1: R-TRIMM74W; RTRIM74W
R1: 1kΩ; 0204/7
R2: 27kΩ; 0204/7
R3, R4: 5kΩ; 0204/7
R5: 220Ω; 0204/7
R6: 600Ω; 0204/7
T1: 2SC458; TO92-ECB

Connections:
3V3: ESP8266_NODEMCU.3V3@1 (3V3), ESP8266_NODEMCU.3V3@2 (3V3), ESP8266_NODEMCU.3V3@3 (3V3), IC1.8 (V+), MCP3301.1 (VREF), MCP3301.8 (VDD), R4.2, R6.2
GND: C1.2, ESP8266_NODEMCU.GND@1 (GND), ESP8266_NODEMCU.GND@2 (GND), ESP8266_NODEMCU.GND@3 (GND), ESP8266_NODEMCU.GND@4 (GND), IC1.4 (V-), J1.2, LED1.K (C), MCP3301.4 (VSS), POT1.3 (E), R3.1, T1.B
unnamed: ESP8266_NODEMCU.D5, MCP3301.7 (CLK)
unnamed: ESP8266_NODEMCU.A0, POT1.1 (A), R6.1, T1.C
unnamed: ESP8266_NODEMCU.D6, MCP3301.6 (DOUT)
unnamed: ESP8266_NODEMCU.D8, MCP3301.5 (!CS/SHDN)
unnamed: LED1.A, R5.1
unnamed: POT1.2 (S), T1.E
unnamed: IC1.7 (OUT), MCP3301.2 (IN(+)), R2.1
unnamed: IC1.1 (OUT), IC1.2 (-IN), MCP3301.3 (IN(-)), R1.2
unnamed: ESP8266_NODEMCU.D0, R5.2
unnamed: IC1.6 (-IN), R1.1, R2.2
V1: IC1.5 (+IN), J1.3
V2: C1.1, IC1.3 (+IN), J1.4, R3.2, R4.1
VCC: ESP8266_NODEMCU.VIN, J1.1

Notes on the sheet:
Chromel
Alumel

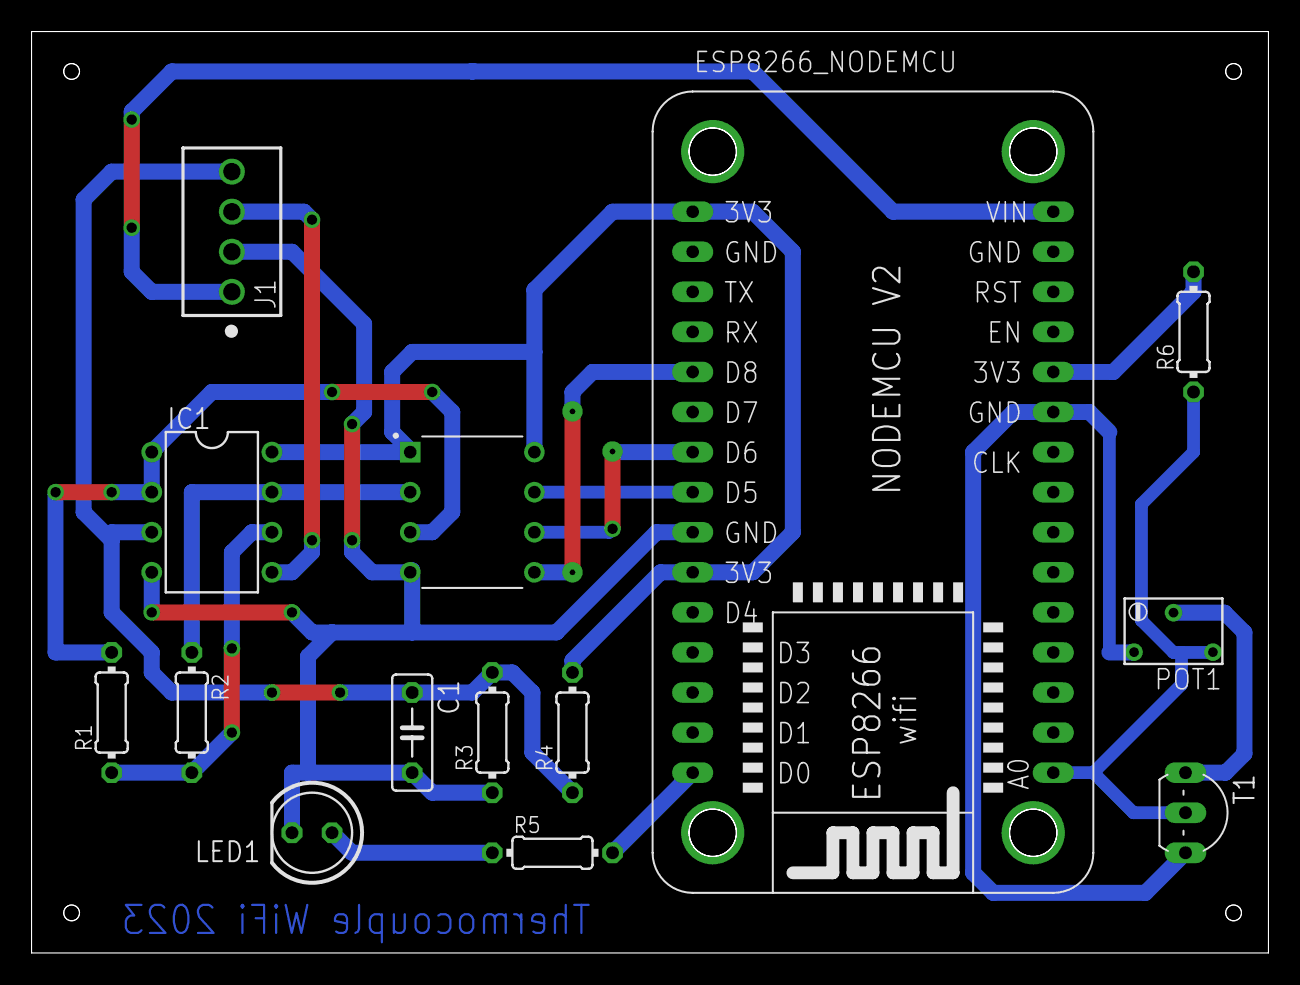
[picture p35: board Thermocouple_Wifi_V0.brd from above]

Board: 2 copper layers, 78.4 x 58.4 mm, 14 parts (0 on the bottom side), 15 nets.

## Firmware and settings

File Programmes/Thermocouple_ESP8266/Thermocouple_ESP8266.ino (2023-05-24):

/* Create a WiFi access point and provide a web server on it.
Just a little test message.  Go to http://192.168.4.1 in a web browser
   connected to this access point to see it.*/   
#include <ESP8266WiFi.h>
#include <SPI.h>

#define Vref 3.3 // tension de reference du MCP3301 en V ici 3.3V
#define Gain 56.22 // gain de l'amplification de la tension mesuree résultant du circuit des 2 AOP = 28.11 mais en pratique environ le double

int led = D0; //led sur le pin D0
const int csPin = D8;  // Chip Select MCP3301
const char *ssid = "Thermocouple-WiFi";// Identifiant WiFi
const char *password = "ENSIBS2023";// Mot de passe WiFi
const int LM335 = A0;

bool sign=0;
int i=0, adcValue=0, z=0;
float tempSF=0, maxi=0, tensionmV=0, mini=0, moy=0, acc=0;

byte highByte=0x00, lowByte=0x00;

// Définir le port de communication TCP
const int serverPort = 12345;

// Créer un objet WiFiServer sur le port spécifié
WiFiServer server(serverPort);

void setup() {
  Serial.begin(115200);
  SPI.begin();
  pinMode(led, OUTPUT); //Instanciation de la LED comme une sortie
  digitalWrite(led, HIGH);
  pinMode(csPin, OUTPUT);
  pinMode(LM335, INPUT);
  digitalWrite(csPin, HIGH);  // Désactive le MCP3301 (slave)
  
  //Creation du point d acces wifi AP
  Serial.print("Configuring access point...");
  /* You can remove the password parameter if you want the AP to be open. */
  WiFi.softAP(ssid, password);
  IPAddress myIP = WiFi.softAPIP();
  Serial.print("AP IP address: ");
  Serial.println(myIP);
  // Commencer à écouter sur le port spécifié
  server.begin();
  Serial.print("Serveur en ecoute sur le port ");
  Serial.println(serverPort);
  Serial.print("En attente de connexions clients");

  delay(100);
  digitalWrite(led, LOW);
}

void loop() {
  digitalWrite(led, LOW);
  // Verifier si un client est connecte
  WiFiClient client = server.available();
  if (client) {
    Serial.println("Nouvelle connexion");
    while (client.connected()) {
      if(z%20==0){digitalWrite(led, HIGH); z=1;}//allume la led tous les 20 cycles d'émissions
      //Gestion mesure Soudure Froidre SF
      tempSF = analogRead(LM335)*3.3/1023;//Converti la valeur numerique en tension
      tempSF = tempSF*100-273;//Tension > kelvin > celsius (temperature soudure froide SF)
      Serial.print("SF : ");Serial.print(tempSF);Serial.println(" °C");
      if(tempSF >= maxi){maxi=tempSF;}
      if(tempSF <= mini | i==1){mini=tempSF;}
      acc += tempSF;
      moy = acc / i;
      i++;

      //Gestion mesure Soudure Chaude SC
      digitalWrite(csPin, LOW);  // Active le MCP3301 (slave)
      // Lit les deux octets de données renvoyés par le MCP3301
      highByte = SPI.transfer(0);
      lowByte = SPI.transfer(0);
      digitalWrite(csPin, HIGH); // Désactive le MCP3301
      // Calcule la valeur de tension à partir des octets lus
      sign = ((highByte << 8) | lowByte) & 0x1000;
      adcValue = ((highByte << 8) | lowByte) & 0x0FFF;//le 13eme bit est le bit de signe
      if(sign==0){//tension positive
        tensionmV = 1000 * adcValue * Vref / 4096 / Gain;
        // Affiche la valeur de tension sur la console serie
        Serial.print("signe : ");Serial.print(sign, BIN);Serial.print("   adcValue : ");Serial.println(adcValue, BIN);
        Serial.print("Tension : ");Serial.print(tensionmV);Serial.println(" mV");
        // Envoyer des données au client
        String data = String(tensionmV) + "," + String(tempSF);
        client.print(data);
        delay(50);
        digitalWrite(led, LOW); 
        delay(50);// periode 100ms soit 10Hz de frequence de transmission
        z++;
        }
      else if(sign==1){//tension negative
        tensionmV = 1000 * (-4096 + adcValue) * Vref / 4096 / Gain;//Complement a deux
        Serial.print("signe : ");Serial.print(sign, BIN);Serial.print("   adcValue : ");Serial.println(adcValue, BIN);
        Serial.print("Tension : ");Serial.print(tensionmV);Serial.println(" mV");
        String data = String(tensionmV) + "," + String(tempSF);
        client.print(data);
        delay(50);
        digitalWrite(led, LOW);     
        delay(50);
        z++;
        }
      else{Serial.print("erreur signe");}
    }
    
    Serial.println("Connexion terminee");
    WiFi.softAPdisconnect(true);//arret du point d acces
    Serial.println("Point d'accès WiFi fermé");
    server.close();
        
    //Creation du point d acces wifi AP
    Serial.print("Configuring access point...");
    /* You can remove the password parameter if you want the AP to be open. */
    WiFi.softAP(ssid, password);
    IPAddress myIP = WiFi.softAPIP();
    Serial.print("AP IP address: ");
    Serial.println(myIP);
    // Commencer à écouter sur le port spécifié
    server.begin();
    Serial.print("Serveur en ecoute sur le port ");
    Serial.println(serverPort);
    Serial.print("En attente de connexions clients");
  }

  delay(500);
  Serial.print(".");
  digitalWrite(led, 0);
}
